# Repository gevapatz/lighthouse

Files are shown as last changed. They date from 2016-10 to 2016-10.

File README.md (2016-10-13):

# Open source Lighthouse tracking

Github repository: <https://github.com/gevapatz/lighthouse>

For details: <http://making.do/lighthouse/>

## Directory layout

`Firmware` has firmware for the Arduino 101 (Intel Curie breakout board in an
Arduino form factor). To build, download the 
[Curie Open Development Kit](https://github.com/01org/CODK-A) 'A' tree, then
build and upload the firmware with:

`make convert-sketch SKETCH=Lighthouse.ino && make compile && make upload
SERIAL_PORT=/dev/ttyACM0`

The firmware will program the FPGA on the Lighthouse shield directly, so
you don't need a separate programming step for that.

`Hardware` has schematics and Gerber files for the Lighthouse tracking FPGA
shield and companion sensor modules, designed to attach to the shield with
solder tab to 2.54mm pitch connector flat flex cable. The Triad Semiconductor
TS3633 breakout boards work just fine with this shield if you don't want to
go cross-eyed building tiny sensor boards. 

Source files are available on CircuitMaker:

FPGA shield: <http://circuitmaker.com/Projects/Details/Geva-Patz/Lighthouse-tracking-FPGA-shield>

Sensor board: <http://circuitmaker.com/Projects/Details/Geva-Patz/Lighthouse-tracking-sensor-board>

`BLE Receiver` is a basic Bluetooth LE receiver for Windows in C#, which
reads output from the Curie and outputs it as a UDP stream.

`Unity` is a sample Unity project which takes in the UDP data stream and
uses it to manipulate a sphere in 3D space. You'll need to manually 
adjust the coordinates of your two lighthouses (auto-calibration coming
soon...)

`STL` contains the STLs and OpenSCAD source for a simple sensor holder for
three TS3633 demo boards from Triad Semiconductor. This is a very early 
prototype; more sensors in a move vareid configuration would track even better. 

## License

- Windows Bluetooth code is based on the demo code for the BGLib library, and
is thus licensed under the same MIT license

- All other software, hardware and 3D models are licensed under the 
Creative Commons Attribution 3.0 license [CC-BY-3.0](https://creativecommons.org/licenses/by/3.0/us/)

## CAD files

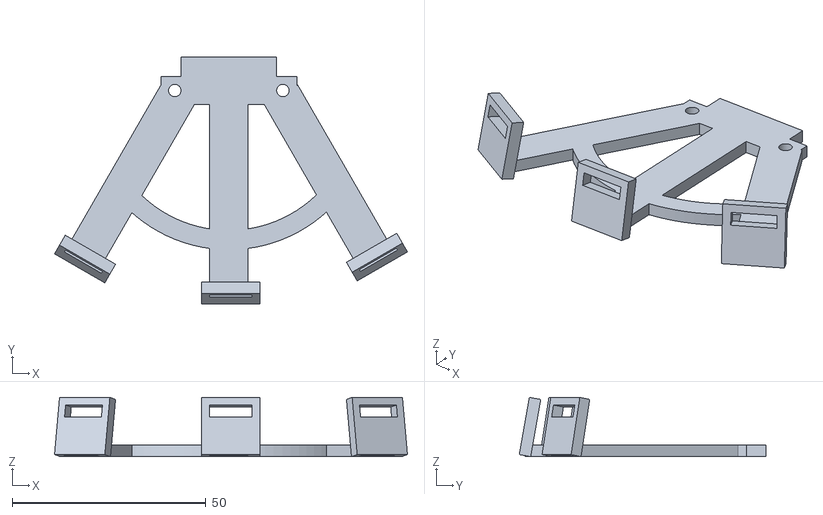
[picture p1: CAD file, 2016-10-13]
STL/sensor_holder_x3.stl
91.1 x 63.7 x 15.3

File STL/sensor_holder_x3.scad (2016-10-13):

ard_hole_dia = 3.2;
ard_hole_spacing = 27.9;
thickness = 3;
extension = 2;
board_tab_len = 5;
arm_width = 10;
arm_length = 50;
sensor_tilt = 10; // degrees up
sensor_height = 12;
connector_width = 11;
connector_height = 3.2; // really 2.6, but compensates for shrinkage
arc_width = 5;

module 2D_arc(w, r, deg=90,fn = 100 ) {
	render() {
		difference() {
			// outer circle
			circle(r=r+w/2,center=true,$fn=fn);
			// outer circle
			circle(r=r-w/2,center=true,$fn=fn);

		//remove the areas not covered by the arc
		translate([sin(90-deg/2)*((r+w/2)*2),
						-sin(deg/2)*((r+w/2)*2)])
			rotate([0,0,90-deg/2])
				translate([((r+w/2))-sin(90-(deg)/4)*((r+w/2)),
							((r+w/2))*2-sin(90-(deg)/4)*((r+w/2))])
					square([sin(90-deg/4)*((r+w/2)*2),
								sin(90-deg/4)*((r+w/2)*2)],center=true);
		translate([-sin(90-(deg)/2)*((r+w/2)*2),
						-sin(deg/2)*((r+w/2)*2)])
			rotate([0,0,-(90-deg/2)])
			  translate([-((r+w/2))+sin(90-(deg)/4)*((r+w/2)),
							((r+w/2))*2-sin(90-(deg)/4)*((r+w/2))])
					square([sin(90-deg/4)*((r+w/2)*2),
								sin(90-deg/4)*((r+w/2)*2)],center=true);
		}
	}
}

module 3D_arc(w, r, deg, h,fn) {
	linear_extrude(h)
			2D_arc(w, r, deg,fn);

}


module sensor_arm() {   
    cube([arm_length, arm_width, thickness]);   
    translate([arm_length-thickness/2, 0, 0])
    rotate([90-sensor_tilt,0,90]) {
        difference() {
            translate([-extension,0,0])
            cube([connector_width + extension*2, sensor_height+thickness, thickness]);
            translate([0,sensor_height+thickness-connector_height-extension, -0.1])
                cube([connector_width, connector_height, thickness+0.2]);
        }
    }
}

difference() {
    union(){
        translate([(ard_hole_spacing+ard_hole_dia)/2 + extension,0,0])
        rotate([0,0,180])
            3D_arc(arc_width,35, 100, thickness, 100);
        cube([ard_hole_spacing + ard_hole_dia + (extension *2), 
            ard_hole_dia + (extension * 2), 
            thickness]);
        translate([0,5,0])
            rotate([0,0,270-30])
                sensor_arm();
        translate([ard_hole_spacing - ard_hole_dia+extension,0,0])
            rotate([0,0,270+30])
                sensor_arm();
        translate([(ard_hole_spacing+ard_hole_dia)/2 + extension-arm_width/2,0,0])
            rotate([0,0,270])
                sensor_arm();
        translate([ard_hole_dia + extension,
                    ard_hole_dia + (extension * 2),0])
            cube([ard_hole_spacing - ard_hole_dia,
                  board_tab_len, thickness]);
    }
    translate([ard_hole_dia/2+extension,
                ard_hole_dia/2+extension,
                -.1])
        cylinder(r=ard_hole_dia/2, h=thickness+0.2, $fn=100);
    translate([ard_hole_dia/2+extension+ard_hole_spacing,
                ard_hole_dia/2+extension,
                -.1])
        cylinder(r=ard_hole_dia/2, h=thickness+0.2, $fn=100);
}

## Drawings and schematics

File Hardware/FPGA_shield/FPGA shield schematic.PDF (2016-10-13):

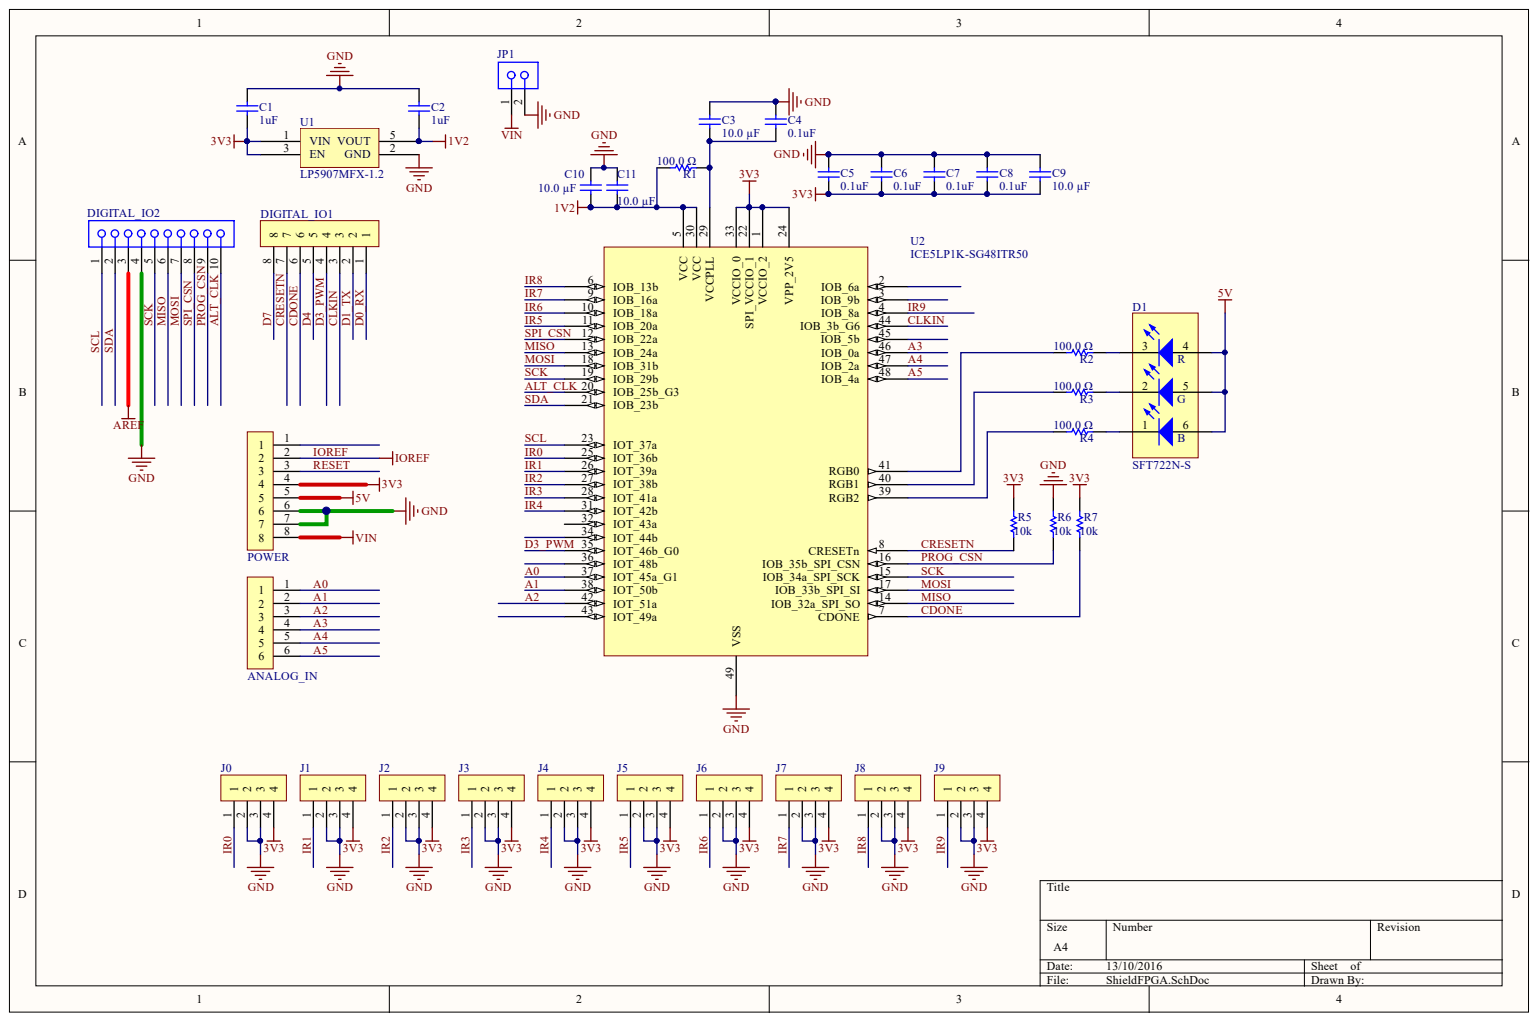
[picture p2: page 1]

IOT_48b 36 | PROG_CSN
IOT_45a_G1 37 | SCK

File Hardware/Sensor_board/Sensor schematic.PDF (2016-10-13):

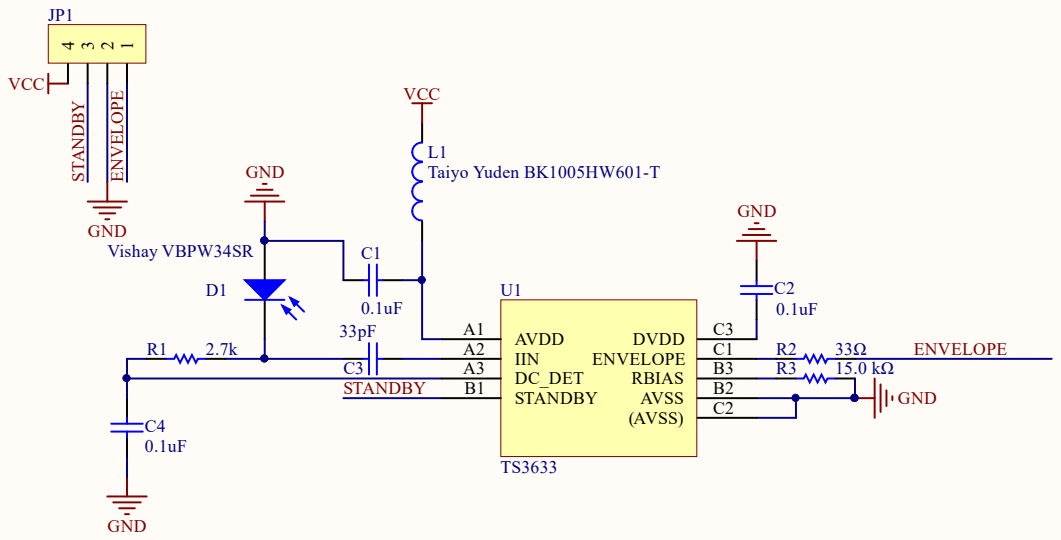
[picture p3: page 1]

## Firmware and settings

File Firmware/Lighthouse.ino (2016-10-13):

#include <CurieI2S.h>
#include <Wire.h>
#include <SPI.h>
#include <CurieBLE.h>
#include <CurieIMU.h>

#define PROGRAM_FPGA
#define SENSOR_BUF_SIZE 128
#define TIMING_BUF_SIZE 40

//#define DEBUG

#ifdef PROGRAM_FPGA
// generate bitmap using convert_bitmap.pl

#include "fpga_bitmap.h"
#endif

// The Intel Curie datasheet claims that the 32 MHz system clock is exported
// on pin PLT_CLK_0 (ball E3, routed to Arduino pin 8 on the 101 board) but 
// the Intel firmware refers to this pin as a low speed (32.768 kHz) clock
// pin. Experimentally, when configured as a clock output I was only able
// to observe a 32 kHz clock on this pin, so Fake_I2S is a hack to generate
// a timebase for the FPGA PLL. The hardware I2S is driven at an intentionally
// 'overclocked' 16 MHz. This generates an ugly but stable signal which the
// PLL cleans up and outputs as a 48 MHz base clock signal.

class Fake_I2S : public Curie_I2S {
	void enableInterrupts() {
		// we don't need interrupts, and we don't want to call the code 
		// in the stock ISR which turns of the clock when the Tx buffers
		// are empty, so we override this to disable interrupts
		interrupt_disable(IRQ_I2S_INTR);
	}
};

Fake_I2S FakeI2S;
//I2S_TX -> Pin 7
//I2S_TSK -> Pin 4
//I2S_TSCK -> pin 2

#define ADDR 0x55
#define SS_PIN 10

#define FPGA_RESET A4
#define FPGA_CSN A5	

BLEPeripheral blePeripheral;      
BLEService timerService("19b10010-E8F2-537E-4F6C-D104768A0116");
BLECharacteristic timerCharacteristic("19b10012-E8F2-537E-4F6C-D104768A0116", BLERead | BLENotify, 20);  
BLECharacteristic imuCharacteristic("19b10014-E8F2-537E-4F6C-D104768A0116", BLERead | BLENotify, 16);                              
   
long previousMillis = 0; 


uint32_t sensor_buf[SENSOR_BUF_SIZE];
uint8_t timing_buf[TIMING_BUF_SIZE];
uint32_t timing_data[6];

int imu_buf[8];
struct sensor_state {
	uint32_t v_a;
	uint32_t h_a;
	uint32_t v_b;
	uint32_t h_b;
	uint32_t cnt;
	byte state;
	byte is_vert;
	byte is_b;
	
	sensor_state() {
		is_vert = state = is_b = 0;
		cnt = v_b = h_b = v_a = h_a = 0;
	}
};

sensor_state sensors[10];

void setup()  {
	pinMode(A2, OUTPUT);
#ifdef DEBUG
	digitalWrite(A2, HIGH);
#else
	digitalWrite(A2, LOW);
#endif
	SPI.begin();
	SPI.setClockDivider(8);
	pinMode(SS_PIN, OUTPUT);
	digitalWrite(SS_PIN, HIGH);
	
	Serial.begin(115200); // initialize Serial communication
	//while(!Serial) ;      // wait for serial port to connect.
	delay(1500);
		
	blePeripheral.setLocalName("TrackedObj");
	blePeripheral.setConnectionInterval(6, 13); // ~= 120/60 Hz in 1.25 msec intervals
	blePeripheral.setAdvertisedServiceUuid(timerService.uuid());
	blePeripheral.addAttribute(timerService);
	blePeripheral.addAttribute(timerCharacteristic);
	blePeripheral.addAttribute(imuCharacteristic);
	for(byte i=0;i<SENSOR_BUF_SIZE;++i)
		sensor_buf[i] = 0;
	for(byte i=0;i<6;++i)
		timing_data[i] = 0;
	for(byte i=0;i<TIMING_BUF_SIZE;++i)
		timing_buf[i] = 0;
	for(byte i=0;i<8;++i)
		imu_buf[i] = 0;
	timerCharacteristic.setValue((unsigned char *)sensor_buf, 20);
	imuCharacteristic.setValue((unsigned char *)sensor_buf, 16);

	Serial.println("Starting");
	// advertise the service
	blePeripheral.begin();
	CurieIMU.begin();
	// I2S has to start AFTER BLE or the chip hangs!
	FakeI2S.begin(0x00020002, I2S_32bit);
	FakeI2S.setI2SMode(PHILIPS_MODE);
	FakeI2S.initTX();
	//start filling the tx buffer
	FakeI2S.pushData(0xFFFFFFFF);
	FakeI2S.pushData(0x00000000);
	FakeI2S.pushData(0xDEADFACE);
	FakeI2S.pushData(0x10101010);
	//Start Transmission
	FakeI2S.startTX();
	
	// drive A5 high with the 101 board on a stable surface to 
	// calibrate the IMU
	pinMode(A5, INPUT);
	digitalWrite(A5, HIGH);
	if(digitalRead(A5)==LOW) {
		Serial.println("Calibrating IMU");
		CurieIMU.autoCalibrateGyroOffset();
		CurieIMU.autoCalibrateAccelerometerOffset(X_AXIS, 0);
    	CurieIMU.autoCalibrateAccelerometerOffset(Y_AXIS, 0);
    	CurieIMU.autoCalibrateAccelerometerOffset(Z_AXIS, 1);
		Serial.println("Calibration finished");
		while(digitalRead(A5)==LOW)
			;
	}
	digitalWrite(A5, LOW);
	
#ifdef PROGRAM_FPGA	
	SPI.setClockDivider(8);
	pinMode(FPGA_RESET, OUTPUT);
	pinMode(FPGA_CSN, OUTPUT);
	Serial.println("Programming FPGA");
	digitalWrite(FPGA_CSN, LOW);
	digitalWrite(FPGA_RESET, LOW);
	delay(1);
	digitalWrite(FPGA_RESET, HIGH);
	delay(1);
	SPI.transfer(0); // 8 clocks to start
	for(unsigned long i=0; i<fpga_bitmap_len; ++i)
		SPI.transfer(pgm_read_byte_near(fpga_bitmap + i));
	// 100 clocks idle
	for(int i=0; i<13; ++i) 
		SPI.transfer(0);
	digitalWrite(FPGA_CSN, HIGH);
	Serial.println("Programming complete");
#endif

	SPI.setClockDivider(8);

	digitalWrite(SS_PIN, LOW);
	SPI.transfer(0xbf);
	digitalWrite(SS_PIN, HIGH);
	digitalWrite(SS_PIN, LOW);
	Serial.print(SPI.transfer(0xff), HEX);
	Serial.print(' ');
	Serial.print(SPI.transfer(1), HEX);
	Serial.print(' ');
	Serial.print(SPI.transfer(1), HEX);
	Serial.print(' ');
	Serial.print(SPI.transfer(1), HEX);
	Serial.print(' ');
	Serial.println(SPI.transfer(1), HEX);
	digitalWrite(SS_PIN, HIGH);
}

byte pin = 0;
byte v = 0;
void loop() {
	BLECentral central = blePeripheral.central();

  if (central) {
#ifdef DEBUG
    Serial.print("Connected to central [DBG]: ");
#else
	  Serial.print("Connected to central: ");
#endif
    // print the central's MAC address:
    Serial.println(central.address());

    while (central.connected()) {
        update_timers();
		update_imu();
    }
    Serial.print("Disconnected from central: ");
    Serial.println(central.address());
  }
}

uint32_t get_timer(byte idx) {
	uint32_t rc = 0;
	digitalWrite(SS_PIN, LOW);
	SPI.transfer(idx);
	digitalWrite(SS_PIN, HIGH);
	digitalWrite(SS_PIN, LOW);
	SPI.transfer(idx);
	for(byte i=0; i<4;++i) {
		byte v = SPI.transfer(idx);
		rc = (rc << 8) | v;
	}
	digitalWrite(SS_PIN, HIGH);
	return rc;
}

// note that B precedes A in the timing sequence 

#define STATE_IDLE 				0
#define	STATE_WAIT_A_LIVE		1
#define STATE_WAIT_A_SILENCE	2
#define STATE_WAIT_A_PULSE 		3
#define STATE_WAIT_B_SILENCE_1	4
#define STATE_WAIT_A_QUIET		5
#define STATE_WAIT_B_SILENCE_2	6
#define STATE_WAIT_B_PULSE		7

void update_timers() {
	byte i = 0;
	uint16_t changed[2] = { 0x0000, 0x8000};
	bool got_all = true;
	while(i<SENSOR_BUF_SIZE) {
		uint32_t val = get_timer(0);
		if(val>0) 
			sensor_buf[i++] = val;
		else if(i>0) {// val == 0
			while(i<SENSOR_BUF_SIZE)
				sensor_buf[i++] = 0;
			got_all = true;
		}
	}
	for(byte i=0;i<SENSOR_BUF_SIZE && sensor_buf[i]!=0;++i) {
		byte sensor = (sensor_buf[i]&0x0f);
		uint32_t ticks =  (sensor_buf[i]>>24) | (((sensor_buf[i]>>16)&0xff) << 8) | 
							(((sensor_buf[i]>>8)&0xff) << 16);
		bool is_high = (sensor_buf[i]&0x40);
#ifdef DEBUG
		if(i<100)
			Serial.print("0");
		if(i<10)
			Serial.print("0");
		Serial.print(i);
		Serial.print(": ");
		if(sensor == 2) {
			Serial.print(sensor_buf[i], HEX);
			Serial.print((sensor_buf[i]&0x40)?" H ":" L ");
			Serial.print(((float)val)/48.0);
		} else {
			Serial.print(sensor_buf[i], HEX);	
		}
		Serial.println(" ");
#endif
		if(is_high) {
			if(sensors[sensor].state == STATE_WAIT_B_SILENCE_1) {
				sensors[sensor].cnt += ticks;
				sensors[sensor].state = STATE_WAIT_A_QUIET;
			} else if(sensors[sensor].state == STATE_WAIT_B_SILENCE_2) {
				sensors[sensor].cnt += ticks;
				sensors[sensor].state = STATE_WAIT_B_PULSE;
			} else if(sensors[sensor].state == STATE_WAIT_A_SILENCE) {
				sensors[sensor].cnt = ticks;
				sensors[sensor].state = STATE_WAIT_A_PULSE;
			}
		} else {
			// low - we have a pulse
			if(ticks<2000) {
				if(sensors[sensor].state == STATE_WAIT_A_PULSE || 
				   sensors[sensor].state == STATE_WAIT_B_PULSE) {
					if(sensors[sensor].is_b) {
						changed[0] |= (1<<sensor);
						if(sensors[sensor].is_vert)
							sensors[sensor].v_b = sensors[sensor].cnt;
						else
							sensors[sensor].h_b = sensors[sensor].cnt;
					} else {
						changed[1] |= (1<<sensor);
						if(sensors[sensor].is_vert)
							sensors[sensor].v_a = sensors[sensor].cnt;
						else
							sensors[sensor].h_a = sensors[sensor].cnt;
					}
				} 
				sensors[sensor].cnt = 0;
				// go back to idle no matter what - if we weren't expecting a 
				// short pulse then we're in some dodgy error state anyway
				sensors[sensor].state = STATE_IDLE;
			} else if ((ticks > 2800 && ticks < 3200) || (ticks > 3800 && ticks < 4200) ||
				(ticks > 3300 && ticks < 3700) || (ticks > 4300 && ticks < 4700)) {
				// rotor 0 start or rotor 1 start 
				sensors[sensor].is_vert = ((ticks > 3300 && ticks < 3700) || 
										   (ticks > 4300 && ticks < 4700));
				sensors[sensor].cnt = 0;
				if(sensors[sensor].state == STATE_WAIT_A_LIVE) {
					sensors[sensor].state = STATE_WAIT_A_SILENCE;	
				} else {
					sensors[sensor].state = STATE_WAIT_B_SILENCE_1;	
					sensors[sensor].is_b = true;
				}
			} else if ((ticks > 4800 && ticks < 5200) || (ticks > 5800 && ticks < 6200) ||
					   (ticks > 5300 && ticks < 5700) || (ticks > 6300 && ticks < 6700) ) {
				// skip states
				if(sensors[sensor].state == STATE_IDLE) {
					sensors[sensor].state = STATE_WAIT_A_LIVE;
					sensors[sensor].is_b = false;
				} else if(sensors[sensor].state == STATE_WAIT_A_QUIET) {
					sensors[sensor].cnt += ticks;
					sensors[sensor].state = STATE_WAIT_B_SILENCE_2;
				} else {
					// something weird happened - give up
					sensors[sensor].state = STATE_IDLE;
				}
			} // end if ticks == 
		} // end if hi/lo
	}
	for(byte i = 0;i<18;++i) { 
		byte shift = (2 - (i%3)) * 8;
		timing_buf[i] = ((i/3)%2)==0?((sensors[i/6].h_b>>shift) & 0xff): 
			((sensors[i/6].v_b>>shift) & 0xff);
	}
	timing_buf[18] = changed[0]>>8;
	timing_buf[19] = changed[0]&0xff;
	timerCharacteristic.setValue((unsigned char *)timing_buf, 20);
	for(byte i = 0;i<18;++i) {
		byte shift = (2 - (i%3)) * 8;
		timing_buf[i] = ((i/3)%2)==0?((sensors[i/6].h_a>>shift) & 0xff): 
			((sensors[i/6].v_a>>shift) & 0xff);
	}
	timing_buf[18] = changed[1]>>8;
	timing_buf[19] = changed[1]&0xff;
	timerCharacteristic.setValue((unsigned char *)timing_buf, 20);
}

void update_imu() {
	CurieIMU.readMotionSensor(imu_buf[0], imu_buf[1], imu_buf[2],
							  imu_buf[3], imu_buf[4], imu_buf[5]);
	*(long *)(&(imu_buf[6])) = millis();
	imuCharacteristic.setValue((unsigned char *)imu_buf, 16);
}
